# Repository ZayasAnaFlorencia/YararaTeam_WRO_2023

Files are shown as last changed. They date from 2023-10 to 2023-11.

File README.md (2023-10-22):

# Yarará Team - WRO Future Engineers Category

We are a passionate robotics team from Misiones, Argentina, competing in the WRO Future Engineers category.

## Project Status

🤖 Currently competing in WRO Future Engineers category.

## Achievements

🥇 We are proud winners of the National Robotics Competition in Argentina.
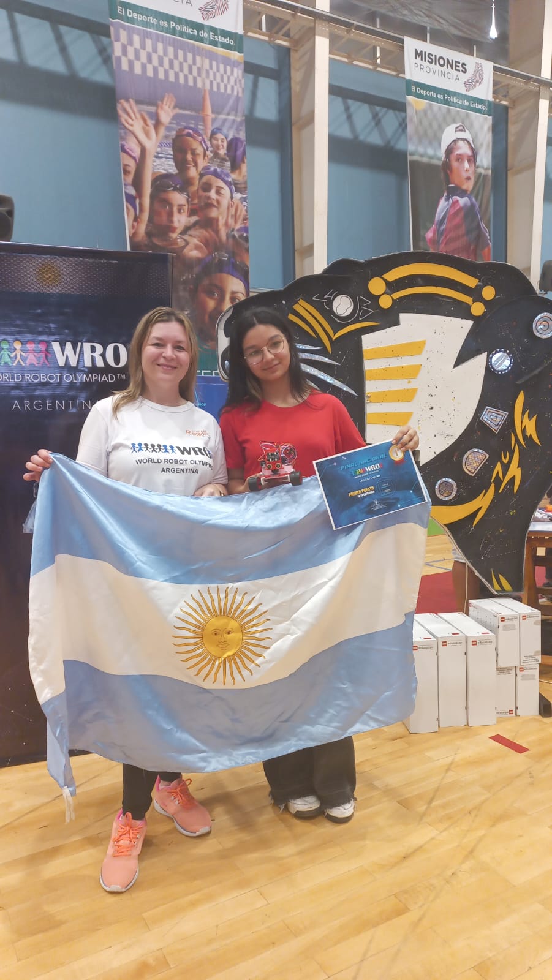
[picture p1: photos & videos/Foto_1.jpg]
First Place


## Our Team

- Campis Juan José - Team Leader
- Zayas Florencia Ana - Designer, Software Developer
- Aguirre Franco Joaquin- Software Developer

## Take a look at our first prototype! Here are some photos:

    It looks messy with all that wirings... 3d printing and cardboards but it worked 😅

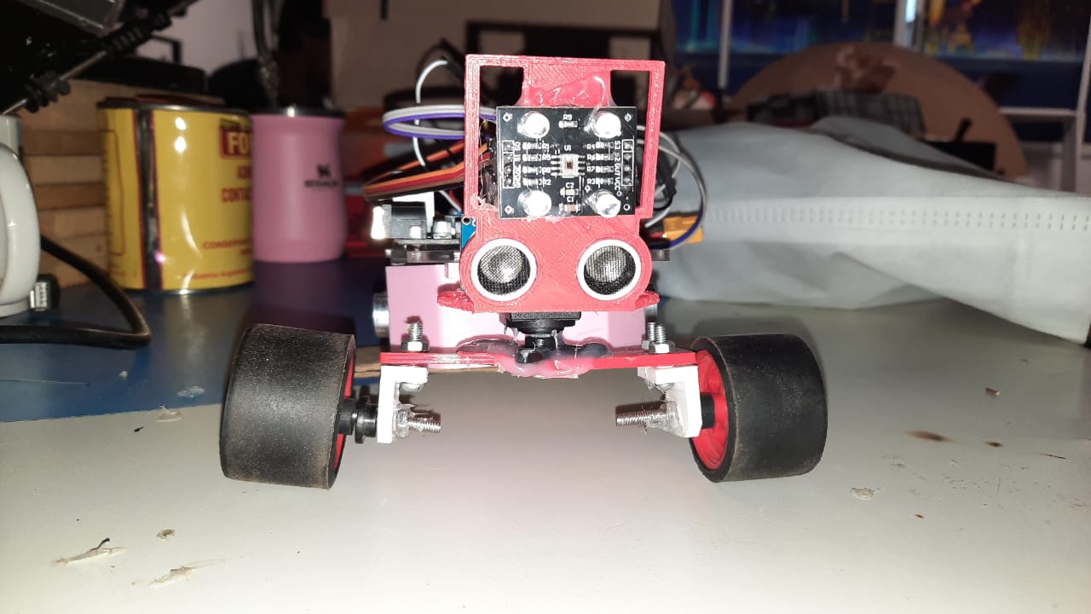
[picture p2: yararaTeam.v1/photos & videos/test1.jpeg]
Eduardo


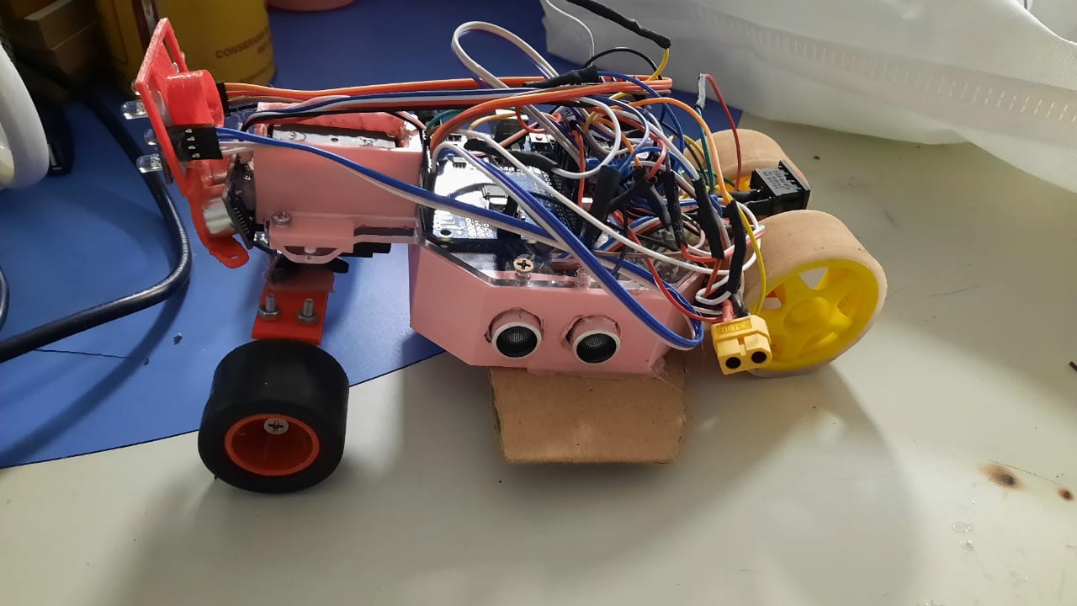
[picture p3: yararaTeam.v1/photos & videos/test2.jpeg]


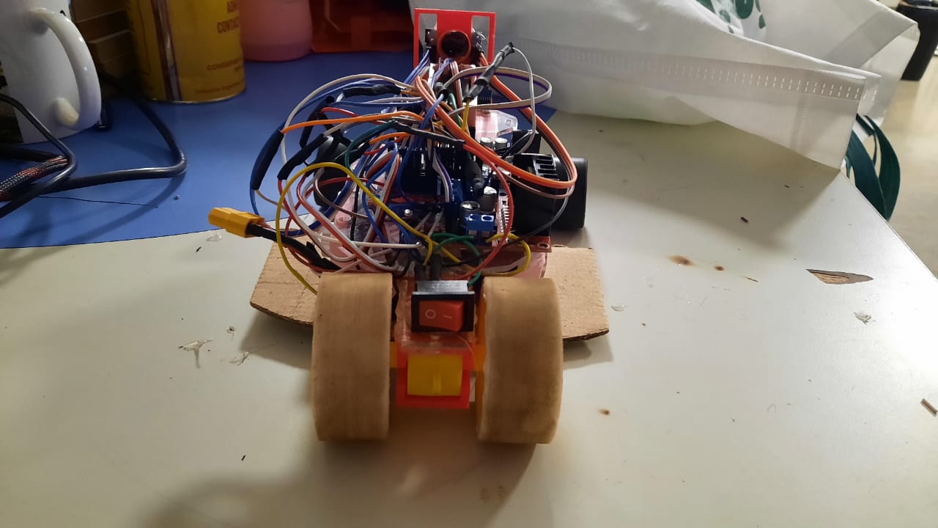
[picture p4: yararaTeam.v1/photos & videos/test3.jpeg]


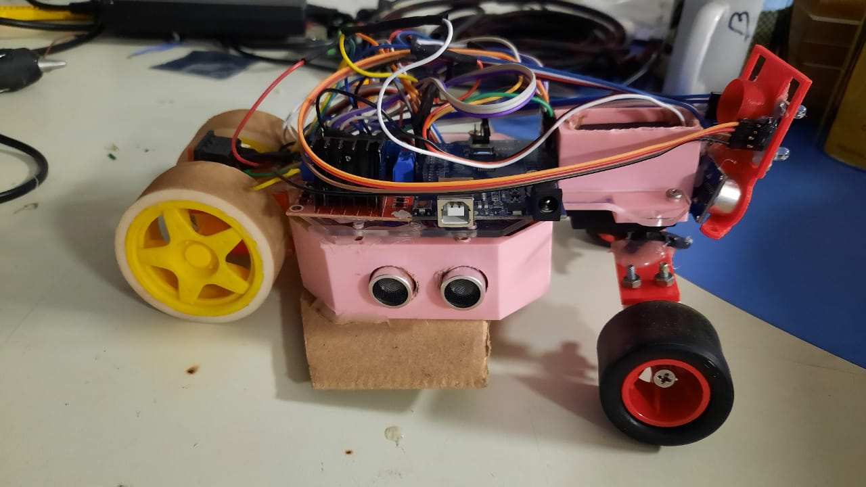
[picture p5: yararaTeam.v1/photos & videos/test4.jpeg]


    We continue practicing and getting better... 
    so we decided added openCV with help of a raspberry pi4.
    
    ⚠️ this develop still in progress! but here are some pics and vids

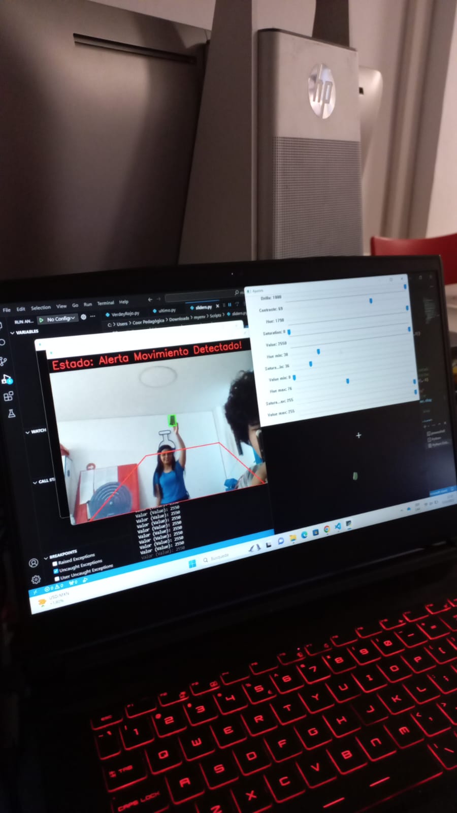
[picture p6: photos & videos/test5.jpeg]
testing object_color detection


demo

## Our flow Diagram (proposed solution)
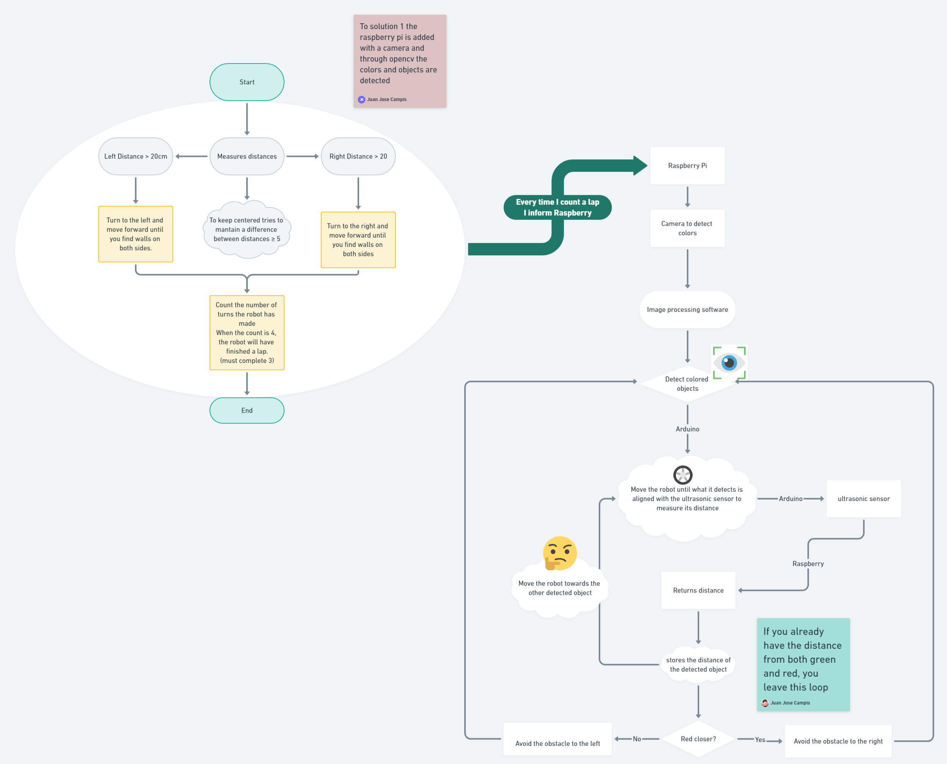
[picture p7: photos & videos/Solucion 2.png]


## Schematic v2 
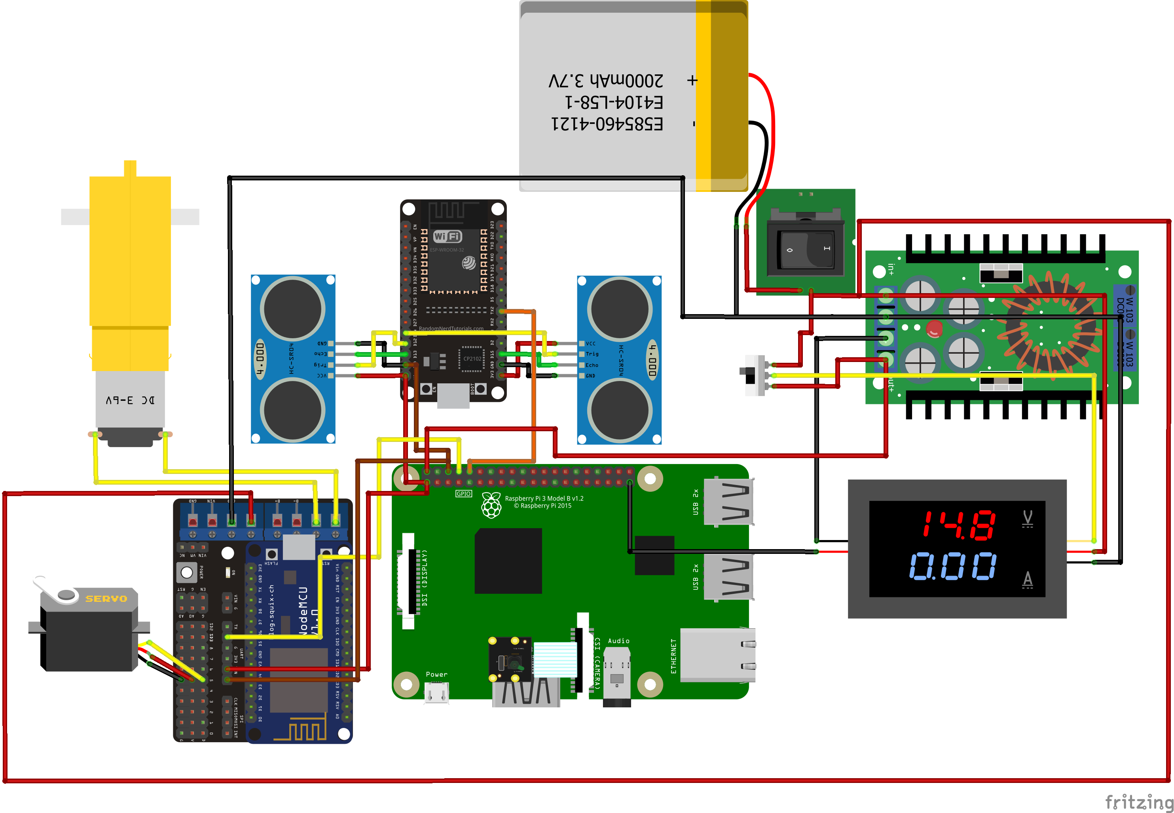
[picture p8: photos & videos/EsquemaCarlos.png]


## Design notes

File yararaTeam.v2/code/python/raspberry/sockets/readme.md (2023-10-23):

para agregar que el archivo sochets.py se ejecute como servicio hay que guardar el archivo en: /etc/systemd/system/mypython.service
y luego agregarlo a la lista de servicios con dietpi-services

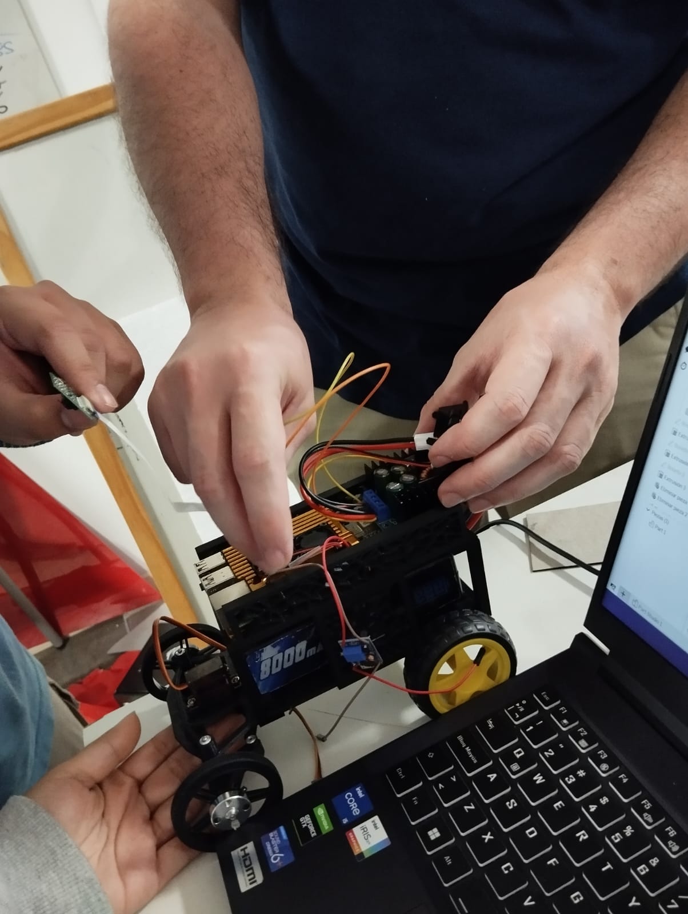
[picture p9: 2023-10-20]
photos & videos/WhatsApp Image 2023-10-11 at 20.48.03 (3) - copia.jpeg

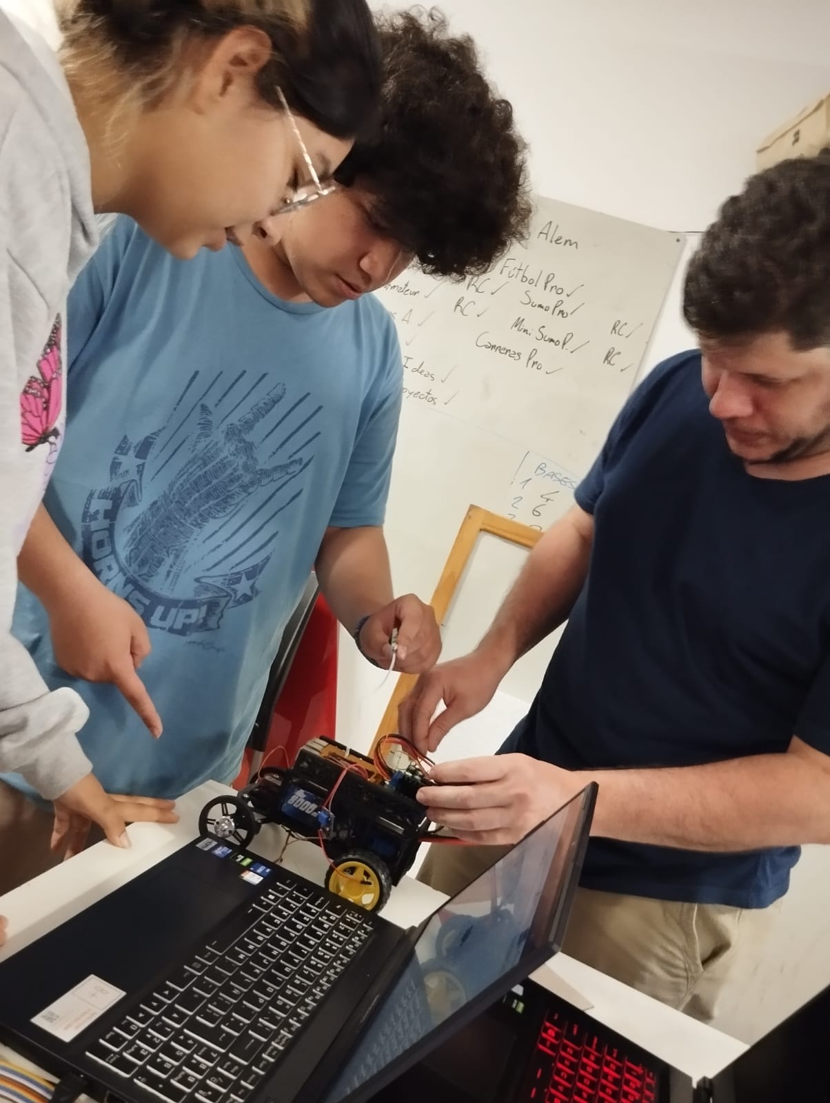
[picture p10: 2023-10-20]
photos & videos/WhatsApp Image 2023-10-11 at 20.48.03 (4) - copia.jpeg

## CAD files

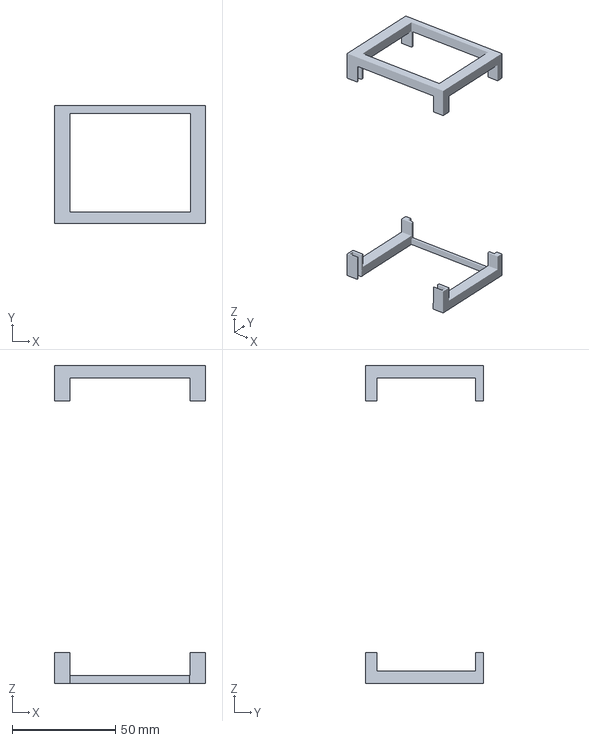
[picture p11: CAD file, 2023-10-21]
yararaTeam.v2/Stl/body/soporte_placas.3mf
73.3 x 57.2 x 154.2 mm

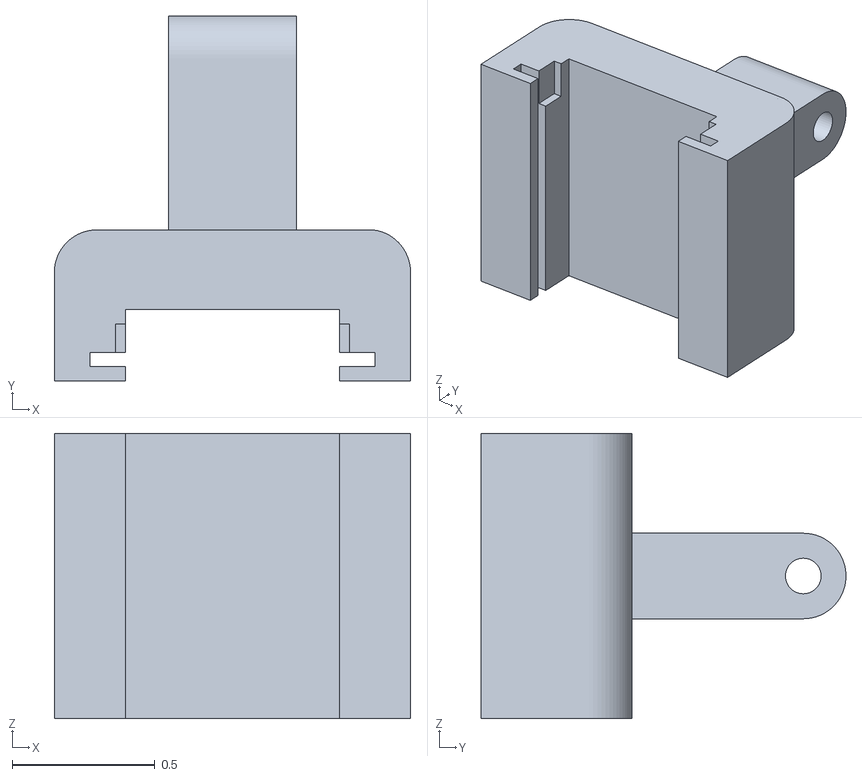
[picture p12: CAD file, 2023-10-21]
yararaTeam.v2/Stl/camera/picam_rounded.stl
1.25 x 1.28 x 1.00

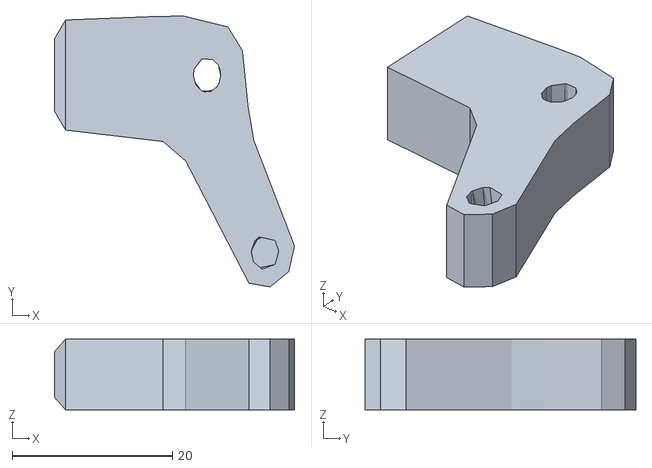
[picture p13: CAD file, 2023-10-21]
yararaTeam.v2/Stl/steering/wheel-arm_L.stl
30.0 x 33.8 x 8.86

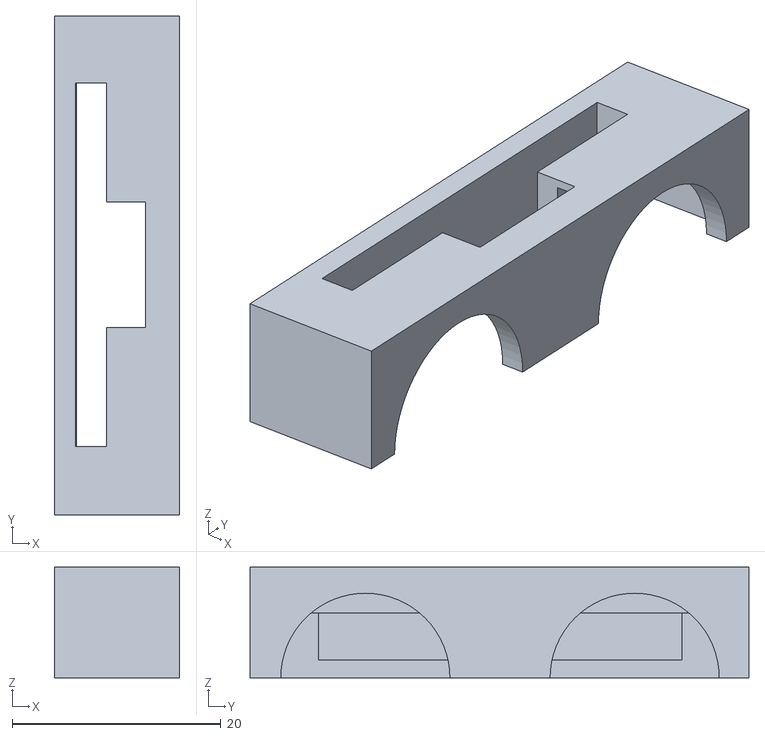
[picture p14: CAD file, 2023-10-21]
yararaTeam.v2/Stl/ultrasonics/soporte ultra.stl
12.0 x 47.8 x 10.6

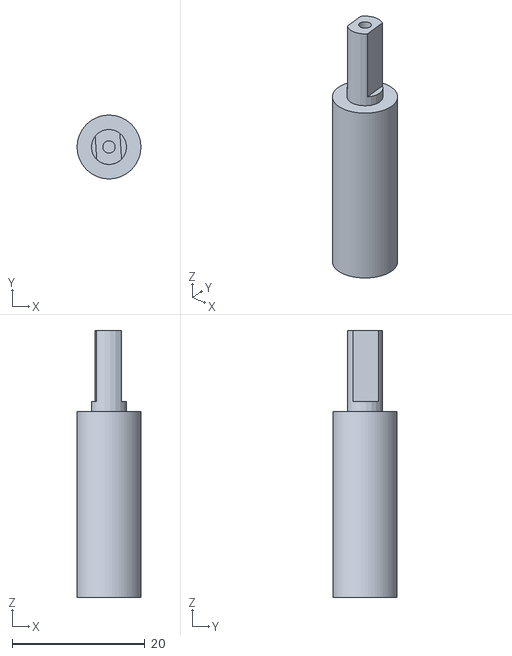
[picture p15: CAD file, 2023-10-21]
yararaTeam.v2/Stl/wheels/eje2.stl
9.60 x 9.60 x 40.2

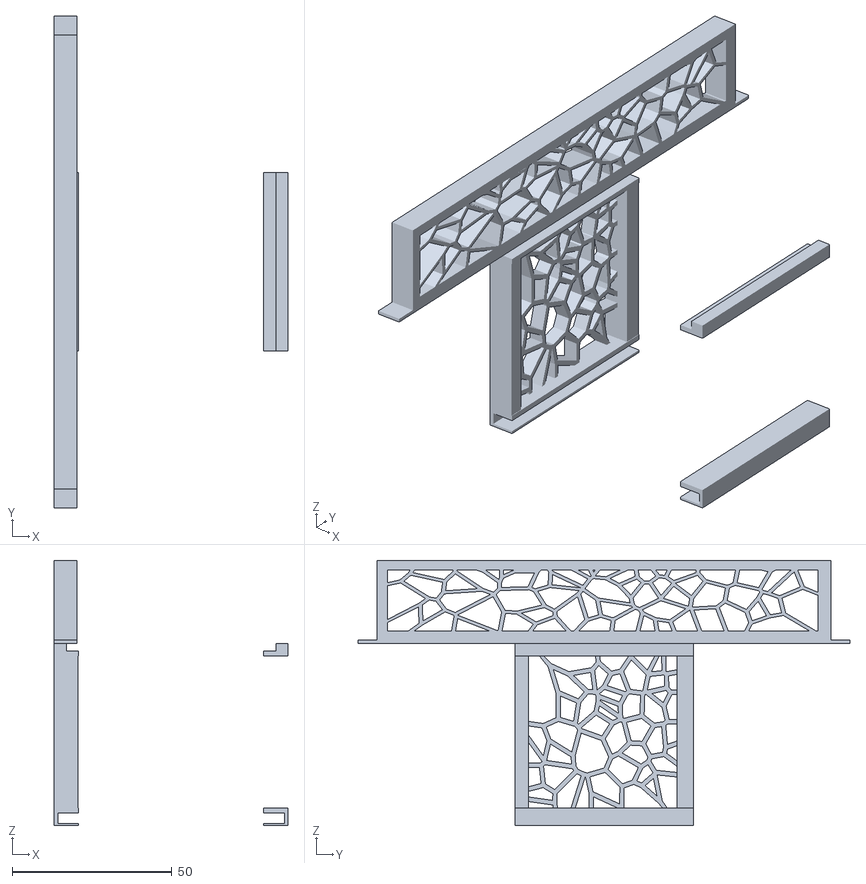
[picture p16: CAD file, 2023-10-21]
yararaTeam.v2/Stl/body/soporte mid.stl
73.3 x 154.2 x 83.2

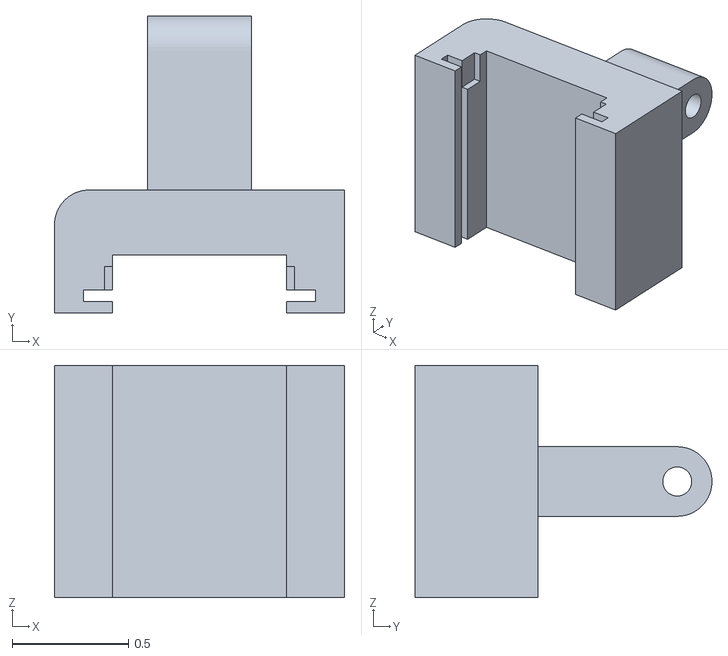
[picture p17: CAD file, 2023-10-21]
yararaTeam.v2/Stl/camera/picam.stl
1.25 x 1.28 x 1.00

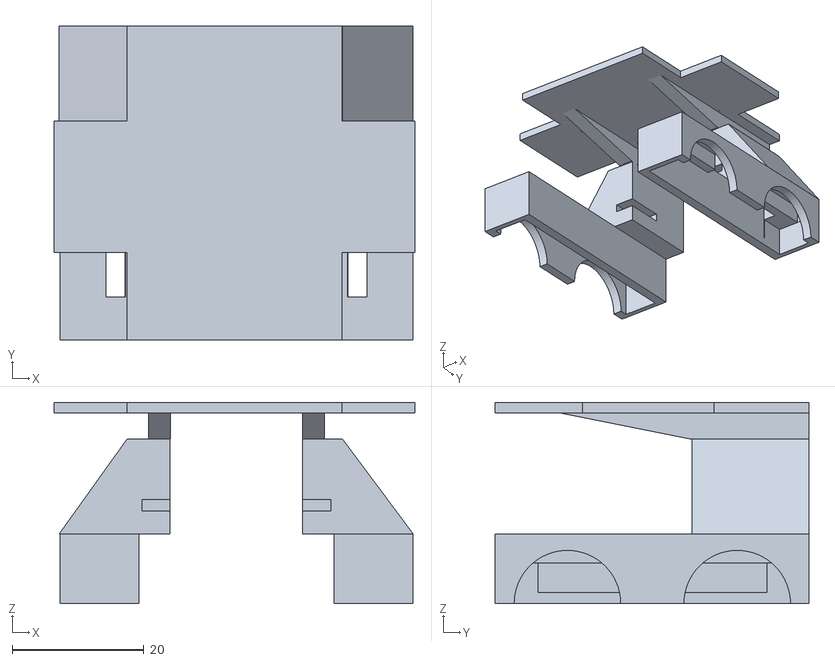
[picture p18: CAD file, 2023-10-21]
yararaTeam.v2/Stl/ultrasonics/soporte ultrasonico.stl
54.9 x 47.8 x 30.6

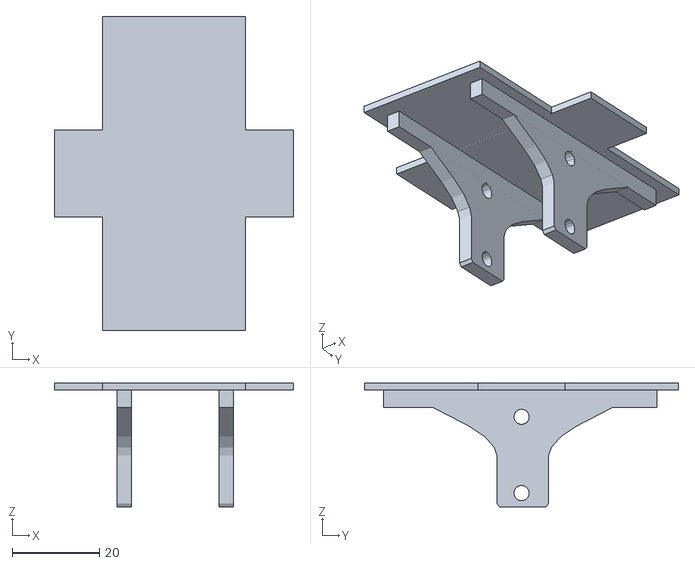
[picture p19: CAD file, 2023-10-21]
yararaTeam.v2/Stl/wheels/MOTORCSOPORTE_ok.stl
54.9 x 72.0 x 28.4

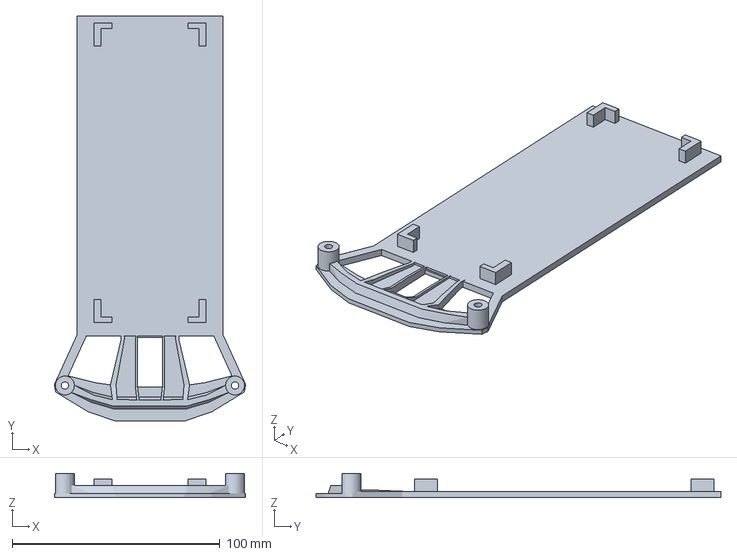
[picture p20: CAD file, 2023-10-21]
yararaTeam.v2/Stl/body/base_bat_completo.3mf
92.2 x 195.1 x 11.6 mm

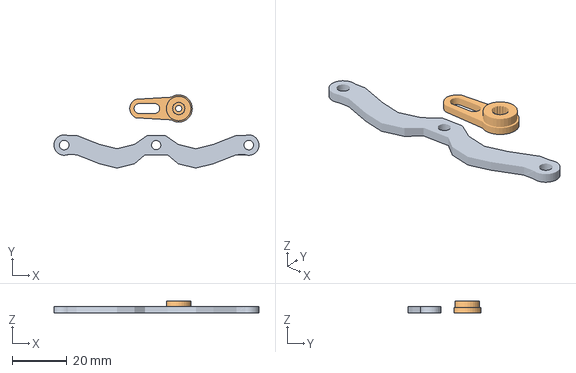
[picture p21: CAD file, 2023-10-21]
yararaTeam.v2/Stl/steering/soporte_steering_cortado2.3mf
75.2 x 26.8 x 4.45 mm
soporte_steering_cortado2.stl
servo.stl

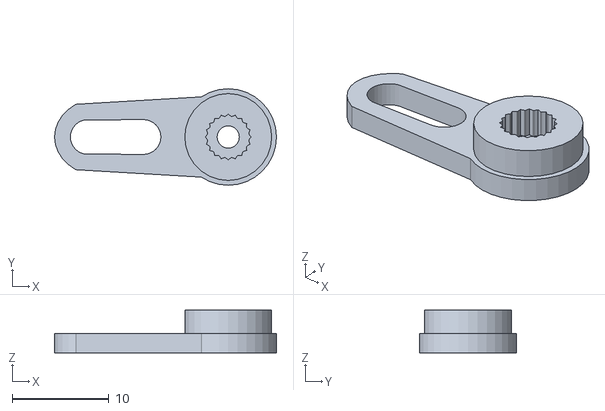
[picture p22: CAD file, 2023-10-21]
yararaTeam.v2/Stl/steering/servo.stl
23.0 x 10.0 x 4.45

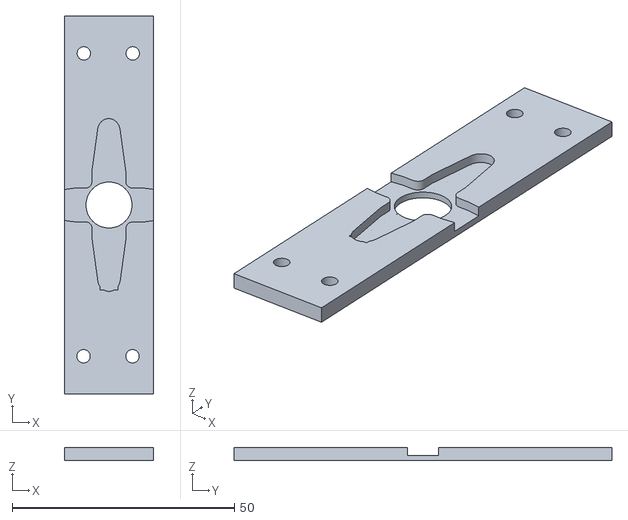
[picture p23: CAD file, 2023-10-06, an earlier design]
yararaTeam.v1/chasis/DIRECCION WRO (7).stl
20.0 x 85.0 x 3.00

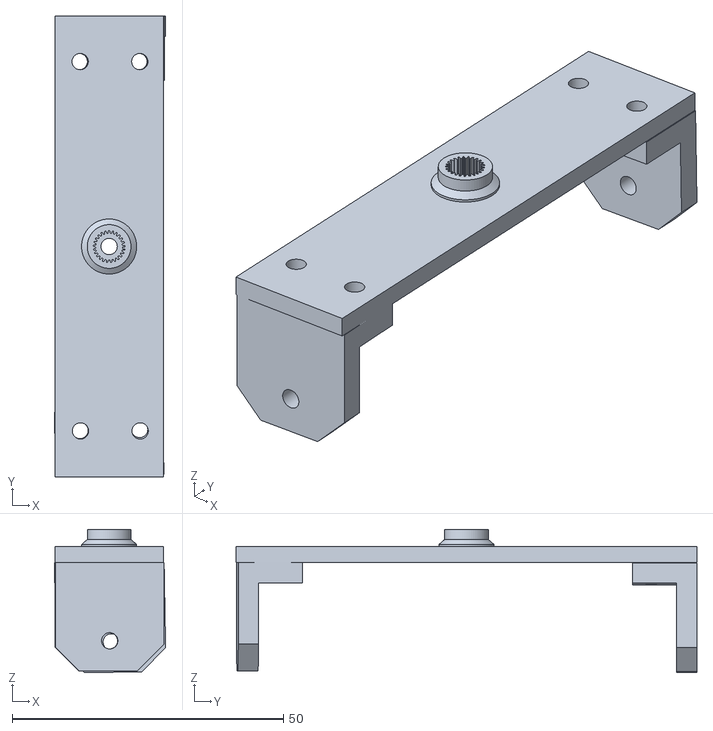
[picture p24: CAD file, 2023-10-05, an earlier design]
yararaTeam.v1/chasis/DIRECCION WRO.stl
20.5 x 85.0 x 26.5

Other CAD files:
yararaTeam.v2/Stl/steering/wheel-arm_R.stl
yararaTeam.v1/chasis/yararaTeam_chasis_v1.stl
yararaTeam.v2/Stl/body/base_bat_completo.stl
yararaTeam.v2/Stl/body/soporte_placas.stl
yararaTeam.v2/Stl/steering/soporte_steering_cortado2.stl

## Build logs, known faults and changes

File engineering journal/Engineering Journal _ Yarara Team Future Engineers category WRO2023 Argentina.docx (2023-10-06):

# Engineering Journal : Yarara Team Future Engineers category WRO2023 Argentina

Participants: Zayas Ana Florencia, Aguirre Franco Joaquin

Mentor: Juan Jose Campis

Country: Argentina

This is the engineering journal of the Yarará Team, proudly representing Argentina in the WRO Panama 2023 competition. Our team consists of two dedicated students and a mentor. Hailing from the province of Misiones in the northwest of Argentina, we started our journey into the world of robotics through the ERM (Escuela de Robótica Misiones).Which is an after-school program that passionately nurtures young minds in the realms of electronics, programming, and design.

Mobility Management

As the regulations for the competition say, we use one dc motor and one servo motor on our robot. In order to make the steering system work, we attached a 3d printed piece which allows both front wheels to move from left to right.This system is pretty simple. However we consider it to be useful. As regards to the dc motor , we attached two wheels to the motor, that way we could make our robot way more efficient and compact.The dc motor (which is in the rear of the chassis) allows the robot to move forward and back.

Power and Sense Management

We took the decision to power the circuit using two batteries; one for the logical part (like the raspberry and the camera) and the other that powers the dc motor. The camera is connected to the raspberry pi while the ultrasound sensors are connected to the arduino.

We decided on the HC SR-04 sensors since we are familiarized with them when it comes to coding but we intend to use more precise sensors soon.

description | we used | we intend to use | quantity
Controller board | nano / ESP32 - 8266 / Pico | ESP32 / ESP8266 | 1
Driver Motor | TB6612 / L298n / L293D | Breakout ESP32 + L293D | 1
Servo Motor | SG90 / MG90S | MG90S | 1
DC Motor w/ wheels | Plastic dc motor | caja reduc azul (metal) | 1
Proximity sensors | HC SR-04 | TOF 400C | 3
For color detection | TCS3200 / rpi cam | rpi cam | 1
SBC | Rpi zero w / Rpi 4 | Raspberry pi 4 | 1
Batteries | Li-po | Li-po | 2
jumpers/wires | Generic | Generic | X
switch | Generic | Generic | 2
Li-po chargers | Generic | Generic | 3
gyroscope | MPU6050 | MPU6050 | 3

Obstacle Management

Pictures – Team and vehicle

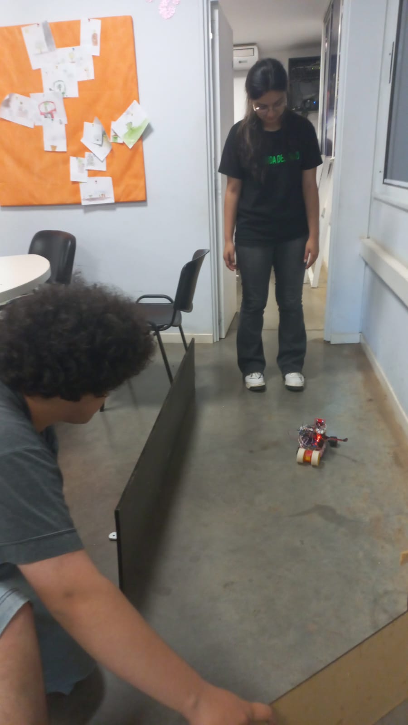
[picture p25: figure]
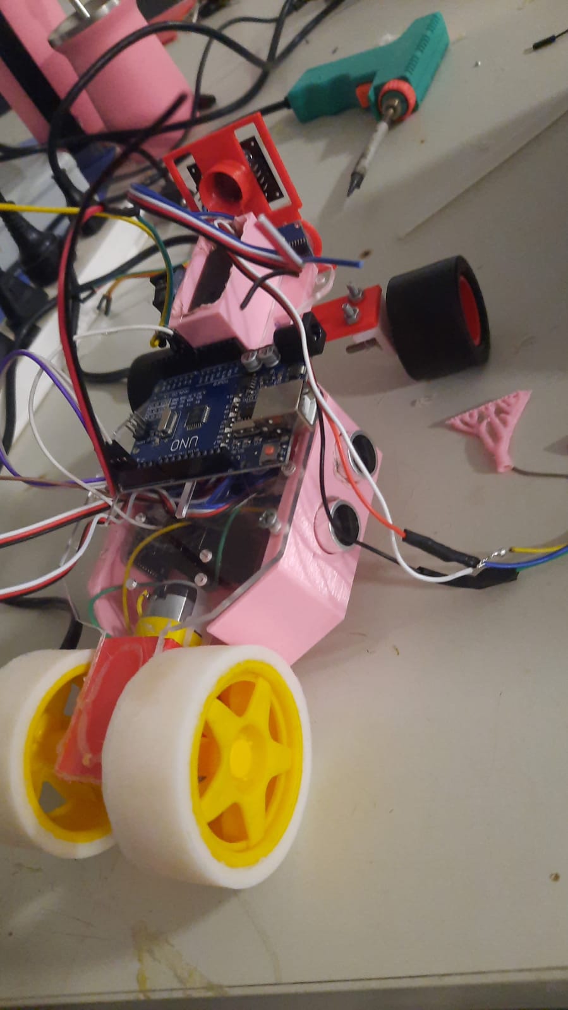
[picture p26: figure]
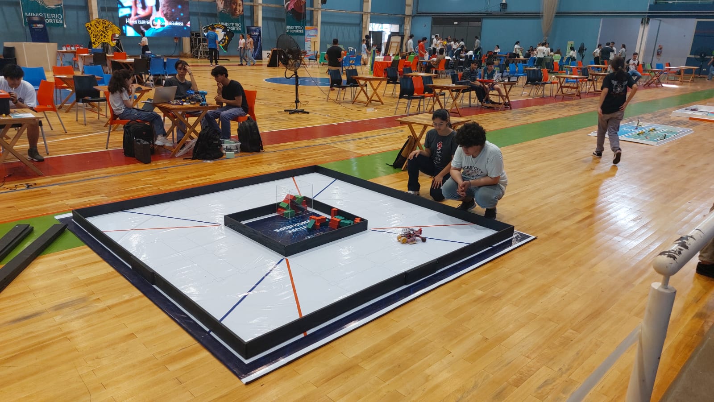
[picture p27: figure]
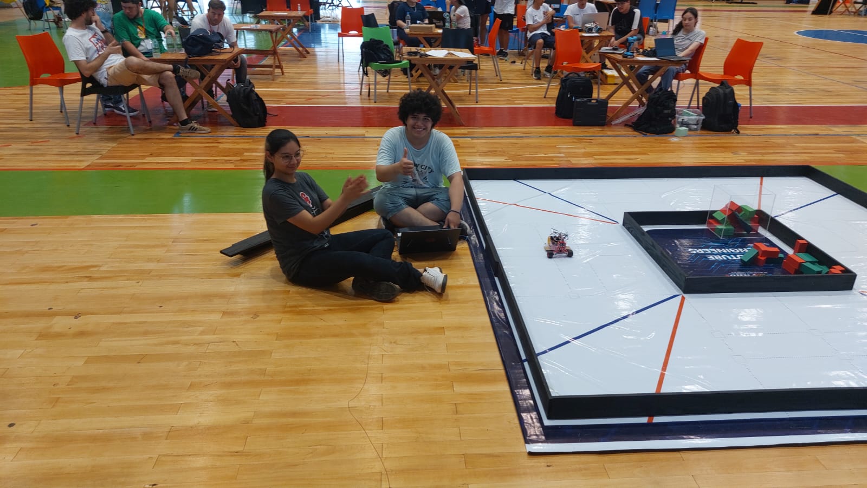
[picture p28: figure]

Engineering Factor

Since this is our first time participating in the WRO, we weren't quite sure how to face this competition. We put together the components for our robots by taking into account our previous experiences using them.For example, we used an arduino uno for our first prototype which we are very familiar with, as well as, the so-called “yellow plastic gearmotor”.

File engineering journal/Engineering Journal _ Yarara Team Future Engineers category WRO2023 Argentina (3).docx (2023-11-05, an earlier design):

# Engineering Journal : Yarara Team

# Future Engineers category WRO2023 Argentina

Participants: Zayas Ana Florencia, Aguirre Franco Joaquin

Mentor: Juan Jose Campis

Country: Argentina

This is the engineering journal of the Yarará Team, proudly representing Argentina in the WRO Panama 2023 competition. Our team consists of two dedicated students and a mentor. Hailing from the province of Misiones in the northwest of Argentina, we started our journey into the world of robotics through the ERM (Escuela de Robótica Misiones).Which is an after-school program that passionately nurtures young minds in the realms of electronics, programming, and design.

# Mobility Management

As the regulations for the competition say, we use one dc motor and one servo motor on our robot. In order to make the steering system work, we attached a 3d printed piece which allows both front wheels to move from left to right.This system is pretty simple. However we consider it to be useful. As regards to the dc motor , we attached two wheels to the motor, that way we could make our robot way more efficient and compact.The dc motor (which is in the rear of the chassis) allows the robot to move forward and back.

# Power and Sense Management

We took the decision to power the circuit using two batteries; one for the logical part (like the raspberry and the camera) and the other that powers the dc motor. The camera is connected to the raspberry pi while the ultrasound sensors are connected to the arduino.

We decided on the HC SR-04 sensors since we are familiarized with them when it comes to coding.In order to avoid obstacles depending on their color we used a camera connected to the raspberry pi.

| specific | fuction | quantity
controller board | raspberry pi 4 | | 1
controller board | esp32 | | 1
controller board | esp8266 | | 1
sensors | hc-sr04 | | 2
driver/motor controller | esp8266 Motor Shield L293DD | | 1
power supply | li-po battery 11.1v , 8 mah | | 1
camera | picam | | 1
steering wheel | servomotor mg90s | | 1
step down | xl 4016 | | 1

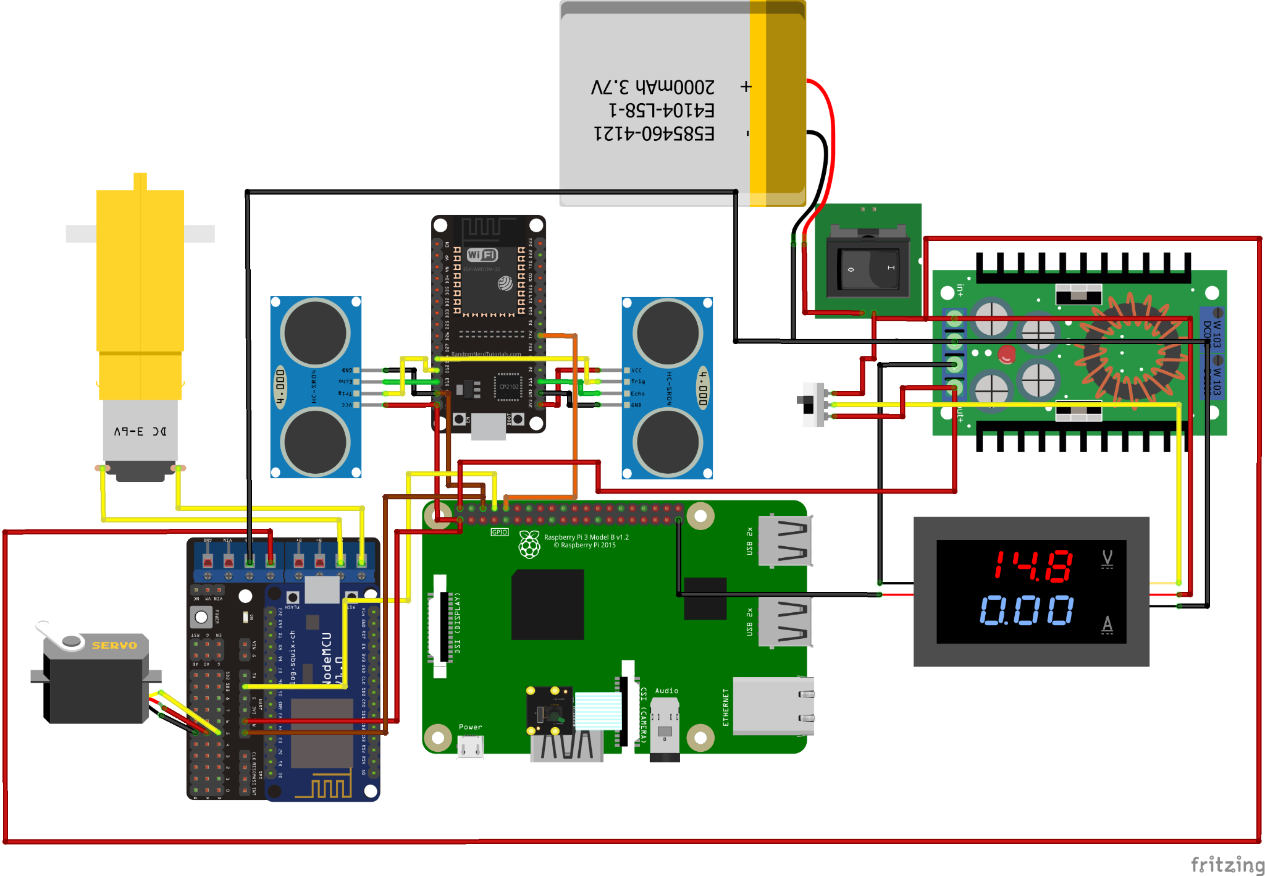
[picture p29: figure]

# Obstacle Management

To prevent the robot from colliding with the walls of the future engineers' game field, we have implemented a dual HC-SR04 module system to analyze distances on both sides of the robot. This setup allows us to make real-time adjustments to the robot's position. If one side's distance reading significantly differs from the other, a servo motor will be activated to steer the vehicle in the opposite direction, re-centering it.

Additionally, we used javascript and node red code to ensure that the robot avoids collisions with both the outer and inner walls of the game field. If the robot is getting too close to a wall, it will trigger the robot to move backward and perform a spin maneuver to navigate away from the obstruction.

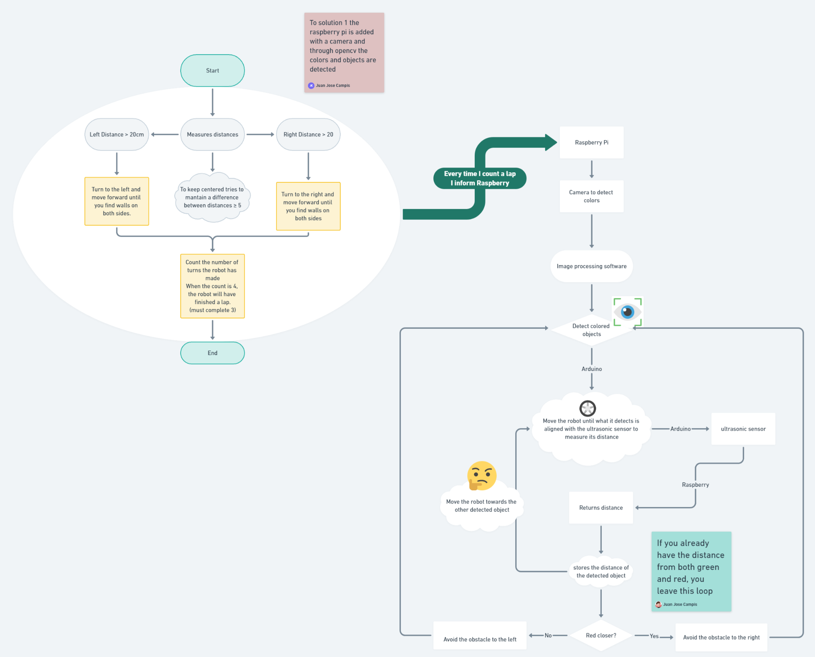
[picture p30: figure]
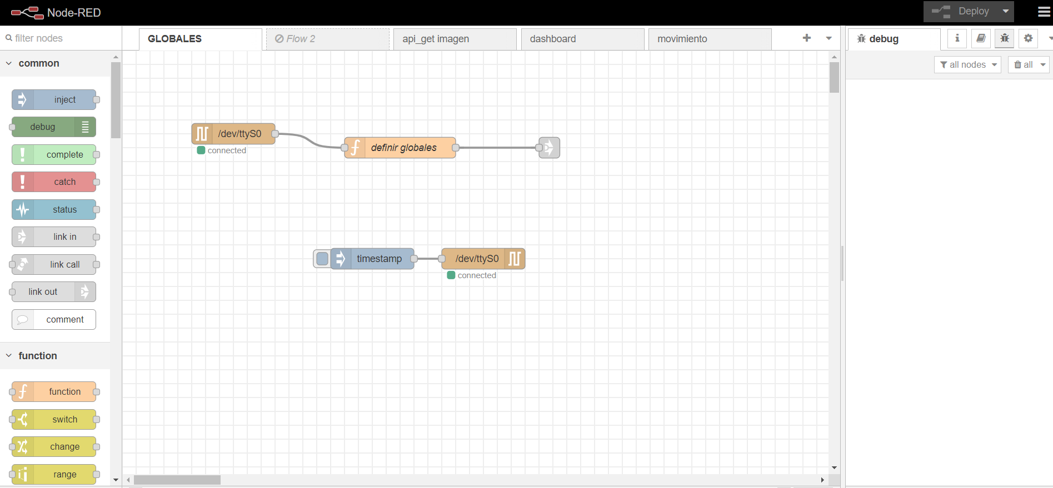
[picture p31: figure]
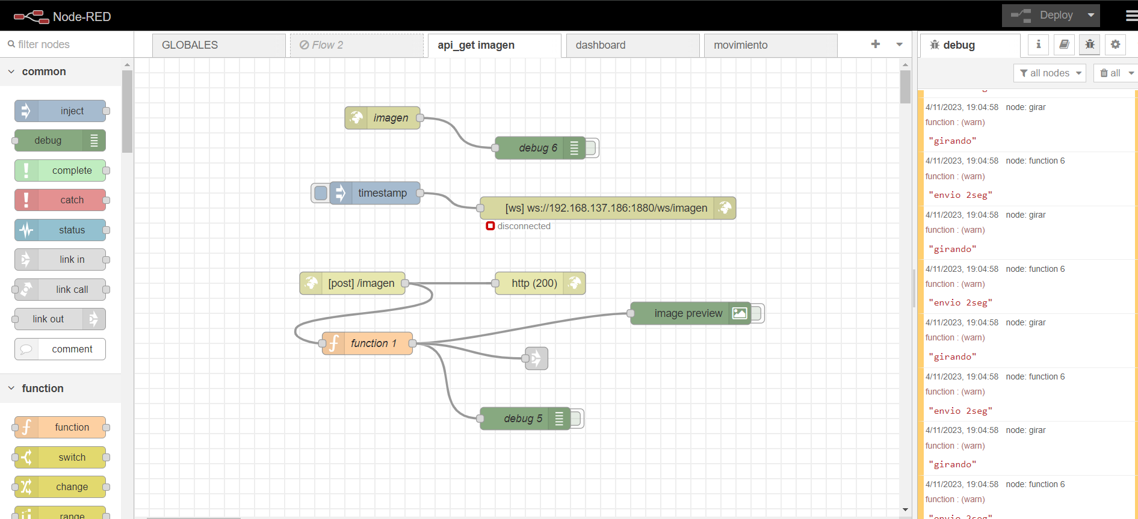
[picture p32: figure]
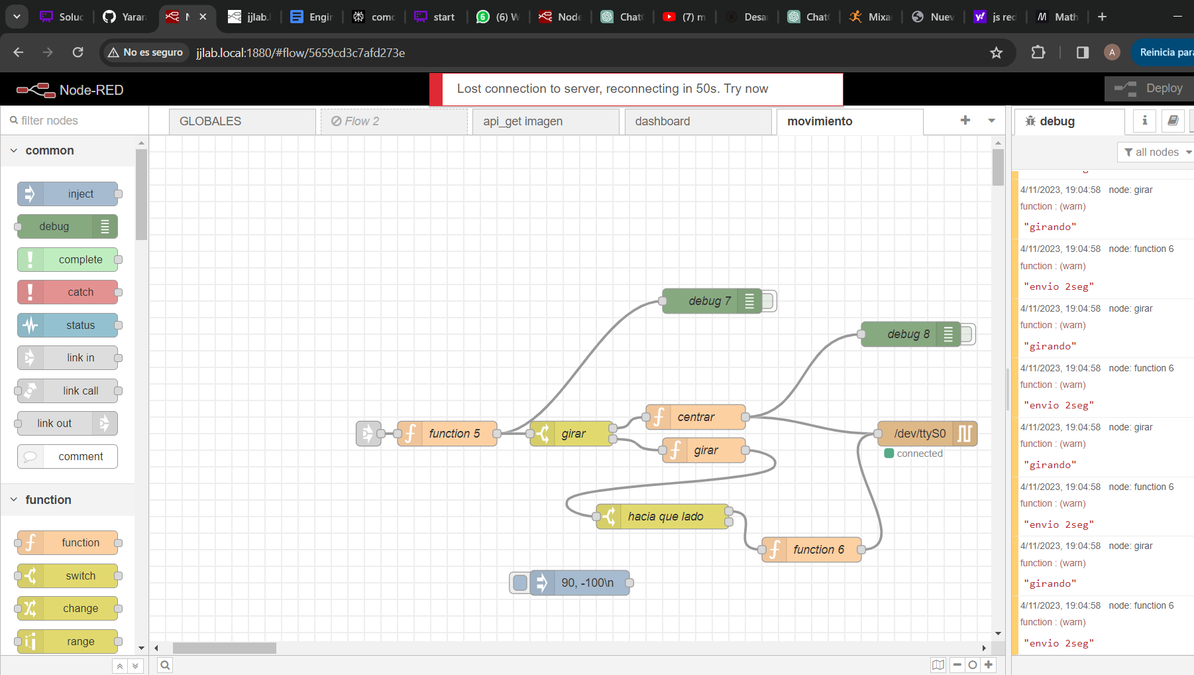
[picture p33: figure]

Pictures – Team and vehicle

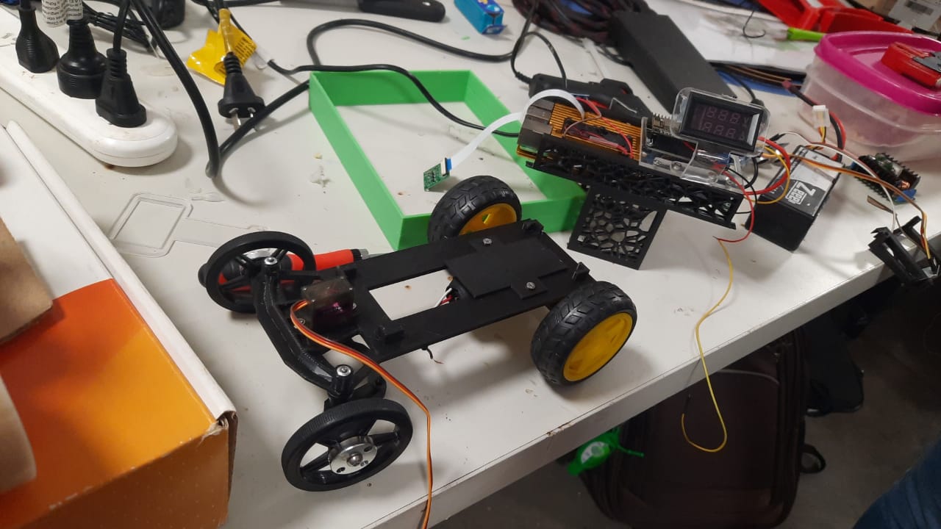
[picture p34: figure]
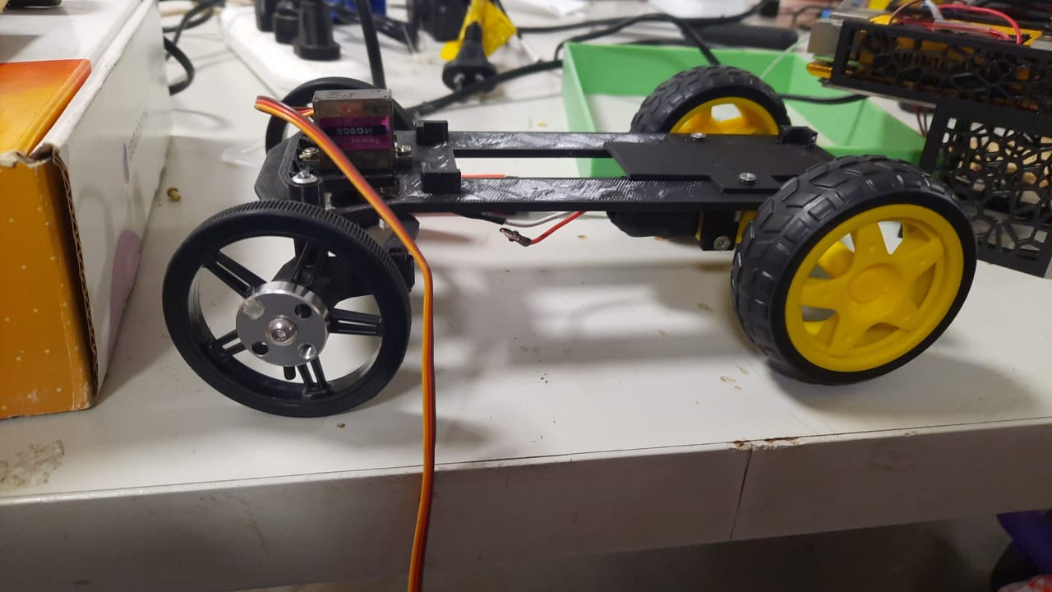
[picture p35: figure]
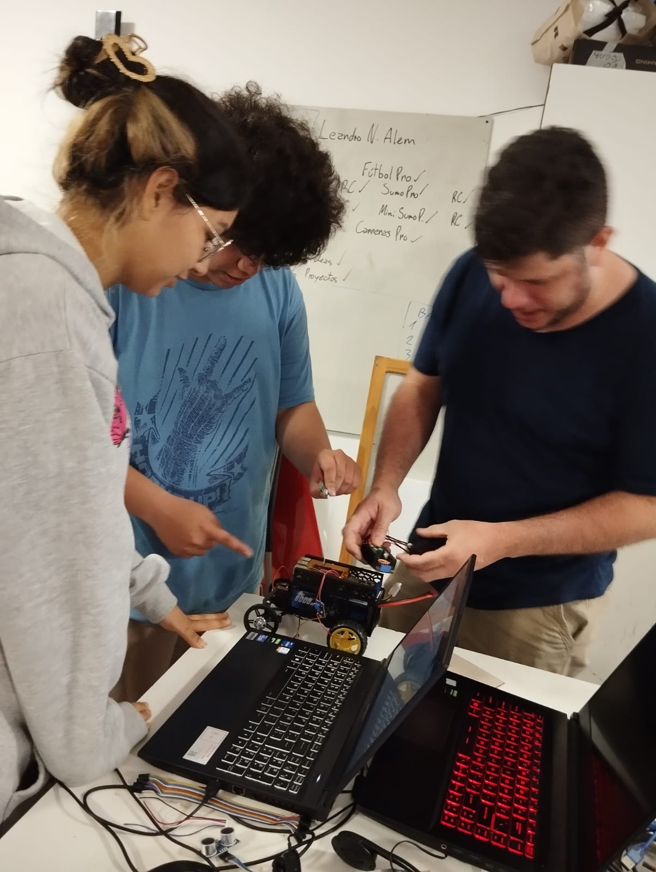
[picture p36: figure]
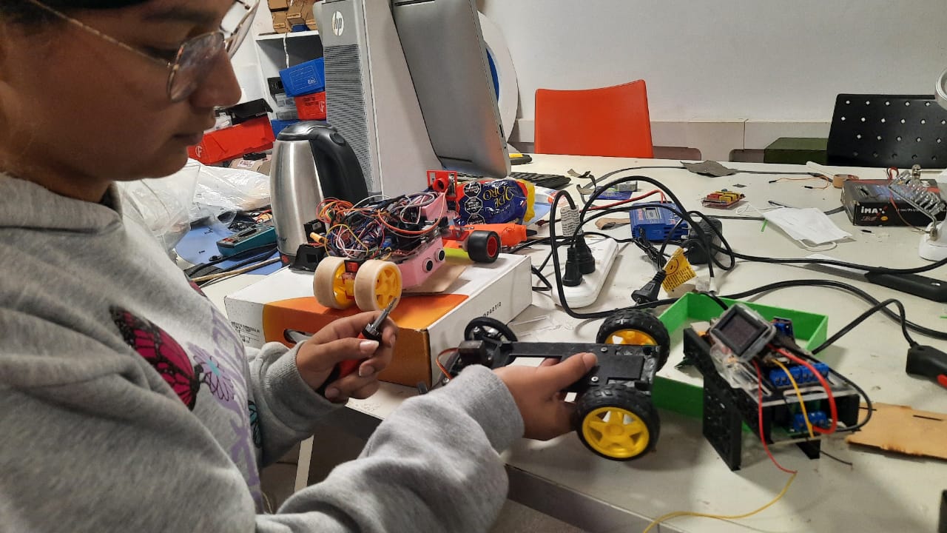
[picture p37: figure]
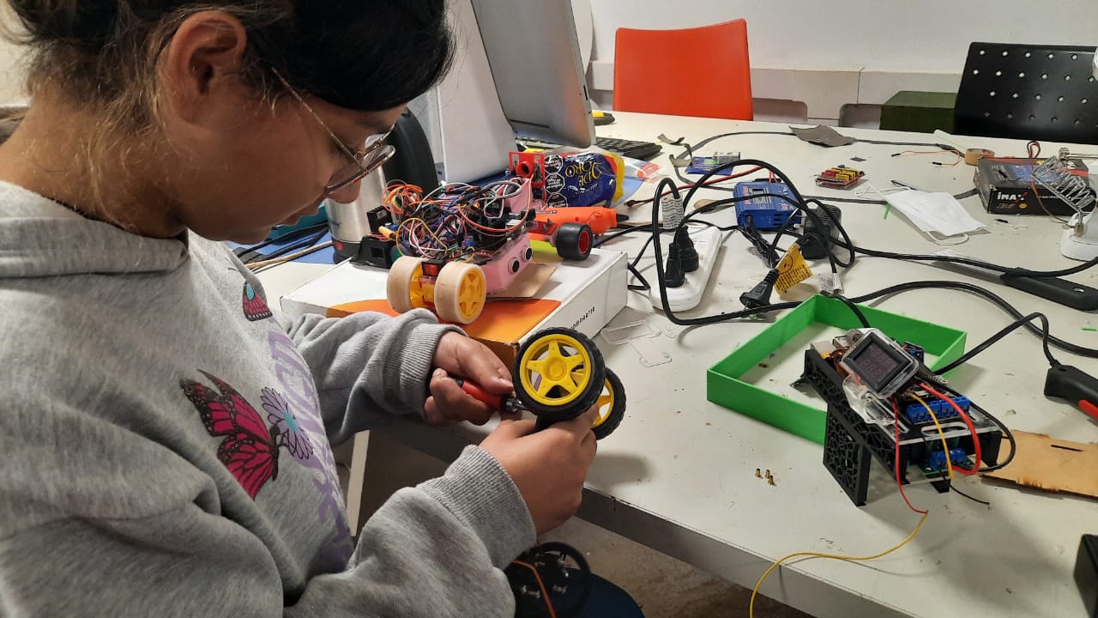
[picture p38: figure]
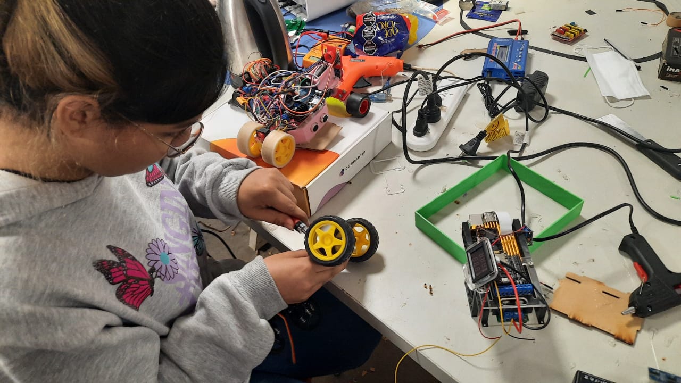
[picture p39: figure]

# Engineering Factor

As newcomers to the World Robot Olympiad (WRO), we approached this challenge with some uncertainty. To assemble our robot, we drew upon our prior experiences with various components. For instance, we initially utilized an Arduino Uno for our first prototype, a platform with which we were very familiar. We also employed the "yellow plastic gearmotor" in our initial setup.

However, after conducting extensive research on different platforms and observing various techniques used by other teams, we had an innovative breakthrough. We decided to make significant changes to our setup. We replaced the Arduino Uno with a Raspberry Pi 4, and we incorporated both an ESP32 and an ESP8266 into our design. We established a serial communication system among these boards to enhance the efficiency of our robot's response during the challenges.

Specifically, we connected the HC-SR04 sensors to the ESP32, which collects data and transmits it to the Raspberry Pi. The Raspberry Pi, in turn, instructs the ESP8266 to control the DC motor and servo motor, allowing us to execute precise and coordinated movements in response to the challenges we encounter.

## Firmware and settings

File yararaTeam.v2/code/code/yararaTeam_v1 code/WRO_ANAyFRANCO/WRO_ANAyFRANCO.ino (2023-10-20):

#include <Mouse.h>

#include <Servo.h>
#include <NewPing.h>

//variables para tomar como referencia
int distanciaInicialIzq = 0;
int distanciaInicialDer = 0;
// Definir pines para los motores L298
const int motor1 = 2;
const int motor2 = 4;
const int pwm = 3;
//para los giros y avances
unsigned long tiempoInicioAvance = 0;  // Variable para controlar el tiempo de avance
const unsigned long duracionAvance = 2000;  // Duración de avance en milisegundos (2 segundos)

// Definir pines para el servo SG90
const int pinServo = 6;
Servo servo;

// Definir pines para los sensores de ultrasonido
const int TRIG_PIN_1 = 7;
const int ECHO_PIN_1 = 8;
const int TRIG_PIN_2 = 9;
const int ECHO_PIN_2 = 10;

// Definir objetos de los sensores de ultrasonido
NewPing s_Izq(TRIG_PIN_1, ECHO_PIN_1, 200);
NewPing s_Der(TRIG_PIN_2, ECHO_PIN_2, 200);

// Definir variables para el contador de vueltas y giros
int contadorVueltas = 0;
int contadorGiros = 0;

void setup() {
  // Inicializar pines de los motores
  pinMode(motor1, OUTPUT);
  pinMode(motor2, OUTPUT);

  // Inicializar el servo
  servo.attach(pinServo);
  // Realizar mediciones iniciales para establecer la referencia
  distanciaInicialIzq = s_Izq.ping_cm();
  distanciaInicialDer = s_Der.ping_cm();
  // Inicializar la comunicación serial
  Serial.begin(9600);
}

void loop() {
  // Realizar mediciones de ultrasonido
  int distanciaIzq = s_Izq.ping_cm();
  int distanciaDer = s_Der.ping_cm();


  // Calcular la diferencia entre las distancias
  int diferenciaDistancias = abs(distanciaIzq - distanciaDer);
if (diferenciaDistancias < 20){
avanzar(255);
}
  // Determinar la dirección más larga
  if ((diferenciaDistancias > 20) && (distanciaIzq > distanciaDer)) {
    // Gira a la izquierda
    giraIzquierda();
    contadorGiros++;
    // Inicia el temporizador de avance
    tiempoInicioAvance = millis();
    // Avanza durante un período de tiempo
    while (millis() - tiempoInicioAvance < duracionAvance) {
      avanzar(127);
    }
  }
  if((diferenciaDistancias > 20) && (distanciaIzq < distanciaDer)) {
    // Gira a la derecha
    giraDerecha();
    contadorGiros++;
    tiempoInicioAvance = millis();
    // Avanza durante un período de tiempo
    while (millis() - tiempoInicioAvance < duracionAvance) {
      avanzar(127);
    }
  }

  // Verificar si se ha completado una vuelta
  if (contadorGiros >= 4) {
    contadorVueltas++;
    contadorGiros = 0;
  }


  // Imprimir información en la comunicación serial
  Serial.print("Distancia Izquierda: ");
  Serial.print(distanciaIzq);
  Serial.print(" cm, Distancia Derecha: ");
  Serial.print(distanciaDer);
  Serial.print(" cm, Vueltas: ");
  Serial.print(contadorVueltas);
  Serial.print(", Giros: ");
  Serial.println(contadorGiros);

  delay(1000);  // Esperar 1 segundo antes de la siguiente medición
}

void giraIzquierda() {
  servo.write(125);
}

void giraDerecha() {
  servo.write(65);     
}
void avanzar(int pot) {
  analogWrite(pwm,pot);
 digitalWrite(motor1,HIGH);  
 digitalWrite(motor2,LOW);  
}

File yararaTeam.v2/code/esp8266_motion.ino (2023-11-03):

#include <Servo.h>

Servo servoMotor;
int ma = 2;
int mpwm = 5;
int servoPin = 14;

void setup() {
  Serial.begin(115200); // Inicializa la comunicación serial a 9600 baudios
  servoMotor.attach(servoPin);
  
  pinMode(ma, OUTPUT);
  pinMode(mpwm, OUTPUT);
}

void loop() {
  if (Serial.available() > 0) {
    String palabra = Serial.readStringUntil('\n'); // Lee una palabra hasta que se reciba una nueva línea
    int separatorIndex = palabra.indexOf(',');
    
  if (separatorIndex != -1) {
    String servoData = palabra.substring(0, separatorIndex);
    String motorData = palabra.substring(separatorIndex + 1);
    int servoValue = servoData.toInt();
    int motorValue = motorData.toInt();
    Serial.print(servoValue);
    Serial.print("  ");
    Serial.println(motorValue);
    Direccion(servoValue);
    Motor(motorValue);
  }
 }
}

void Direccion(int servoValue) {
  servoMotor.write(servoValue);
}

void Motor(int motorValue) {
  if (motorValue < 0){
    digitalWrite(ma, LOW);
    analogWrite(mpwm, abs(motorValue));
  } else {
    digitalWrite(ma, HIGH);
    analogWrite(mpwm, motorValue);
  }
  
}

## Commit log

2023-09-29 se añadio la version 1 del stl
    [yararaTeam_chasis_v1.stl]
2023-10-05 Create ROI_Franco.py
    se creo un archivo de prueba para crear y configurar mascaras para sensar objetos
    A test file was created to create and configure masks to sense objects
2023-10-05 Create DIRECCION WRO.stl
    This is the stl for the 3d printed piece that we used for the steering wheel
    [DIRECCION WRO.stl]
2023-10-06 Create DIRECCION WRO (7).stl
    stl for the steering system with modification
    [DIRECCION WRO (7).stl]
2023-10-06 Create DIRECCION WRO (7).stl
    [DIRECCION WRO (7).stl]
2023-10-06 Create DIRECCION WRO.stl
    [DIRECCION WRO.stl]
2023-10-06 "Organization by Folders"
    [DIRECCION WRO (7).stl, DIRECCION WRO.stl, yararaTeam_chasis_v1.stl]
2023-10-06 "added base codes and flow diagram"
    [DIRECCION WRO (7).stl, DIRECCION WRO.stl]
2023-10-12 Create pruebaesp32.ino
    We used this code to do test on the esp32 controller board and hc-rs04 sensors
2023-10-21 added Stl files
    [MOTORCSOPORTE_ok.stl, base_bat_completo.3mf, base_bat_completo.stl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]
2023-10-22 added py codes for raspberry
2023-10-22 added Schematic
2023-10-22 Schematic added to readme
2023-10-22 Added Schematic .fzz (Fritzing archive)
    [EsquemaCarlos.fzz]
2023-10-23 added code for socket comunication between python and nodered
2023-11-03 fixed code for esp8266_MotorDriver
    [esp8266_motion.ino]
2023-11-04 fixed sensors
